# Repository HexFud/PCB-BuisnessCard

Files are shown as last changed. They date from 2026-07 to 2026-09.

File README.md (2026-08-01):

## PCB-Badge

I built this electronic badge that can be used for example in hachatons or other IT event if you open the project on KICAD you can also customize the writings.

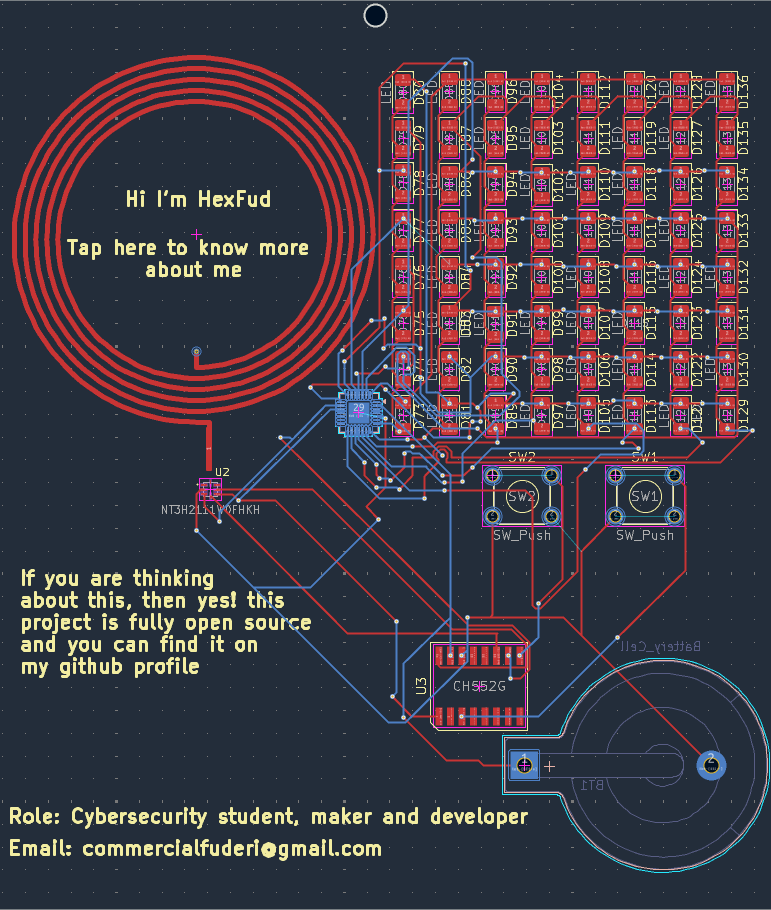
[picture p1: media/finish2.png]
Final work


## How this was made

This project consists only of one PCB 85x100mm and other components like the led matrix controller the microcontoller etc. It also has a NFC tag that can be written with the microcontroller and 2 minigames showed on the 8x8 led matrix on the front.

## How to flash the firmware

1. Install Arduino IDE
   
2. Add the board package going into File -> Preferences and in the additional board URL you paste this https://raw.githubusercontent.com/DeqingSun/ch55xduino/ch55xduino/package_ch55xduino_mcs51_index.json
  
3. Navigate to Tools -> Board -> Boards Manager search ch55xduino and click install
   
4. Plug the microcontroller into the pc and select the correct board you are using in my case a CH552
   
5. You can now flash the firmware

## Notes

If you want to bring your own game on the PCB you're welcome! just fork this repository and then if i'll like your work i am going to mention you guys in the original code. Unfortunatley we only have 2 buttons but in the future I can design another PCB with more functions

## AI decleration

Ai helped me to build the part of the firmware that controls the LED matrix

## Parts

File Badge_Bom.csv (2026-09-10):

Item | Quantity | Unit Price (EUR) | Total Price (EUR) | Unit Price (USD) | Total Price (USD)
IS31FL3731 LED Matrix Driver | 1 | 20.00 | 20.00 | 23.24 | 23.24
NT3H2111W0FHKH NFC IC | 1 | 25.00 | 25.00 | 29.06 | 29.06
CH552G Microcontroller | 1 | 11.00 | 11.00 | 12.78 | 12.78
LED 0603 | 64 | 0.125 | 8.00 | 0.145 | 9.30
Tactile Push Button SMD | 2 | 5.00 | 10.00 | 5.81 | 11.62
Battery Holder Keystone 103 | 1 | 12.00 | 12.00 | 13.95 | 13.95
PCB | 1 | 90.00 | 90.00 | 104.60 | 104.60
TOTAL |  |  | 176.00 |  | 204.55

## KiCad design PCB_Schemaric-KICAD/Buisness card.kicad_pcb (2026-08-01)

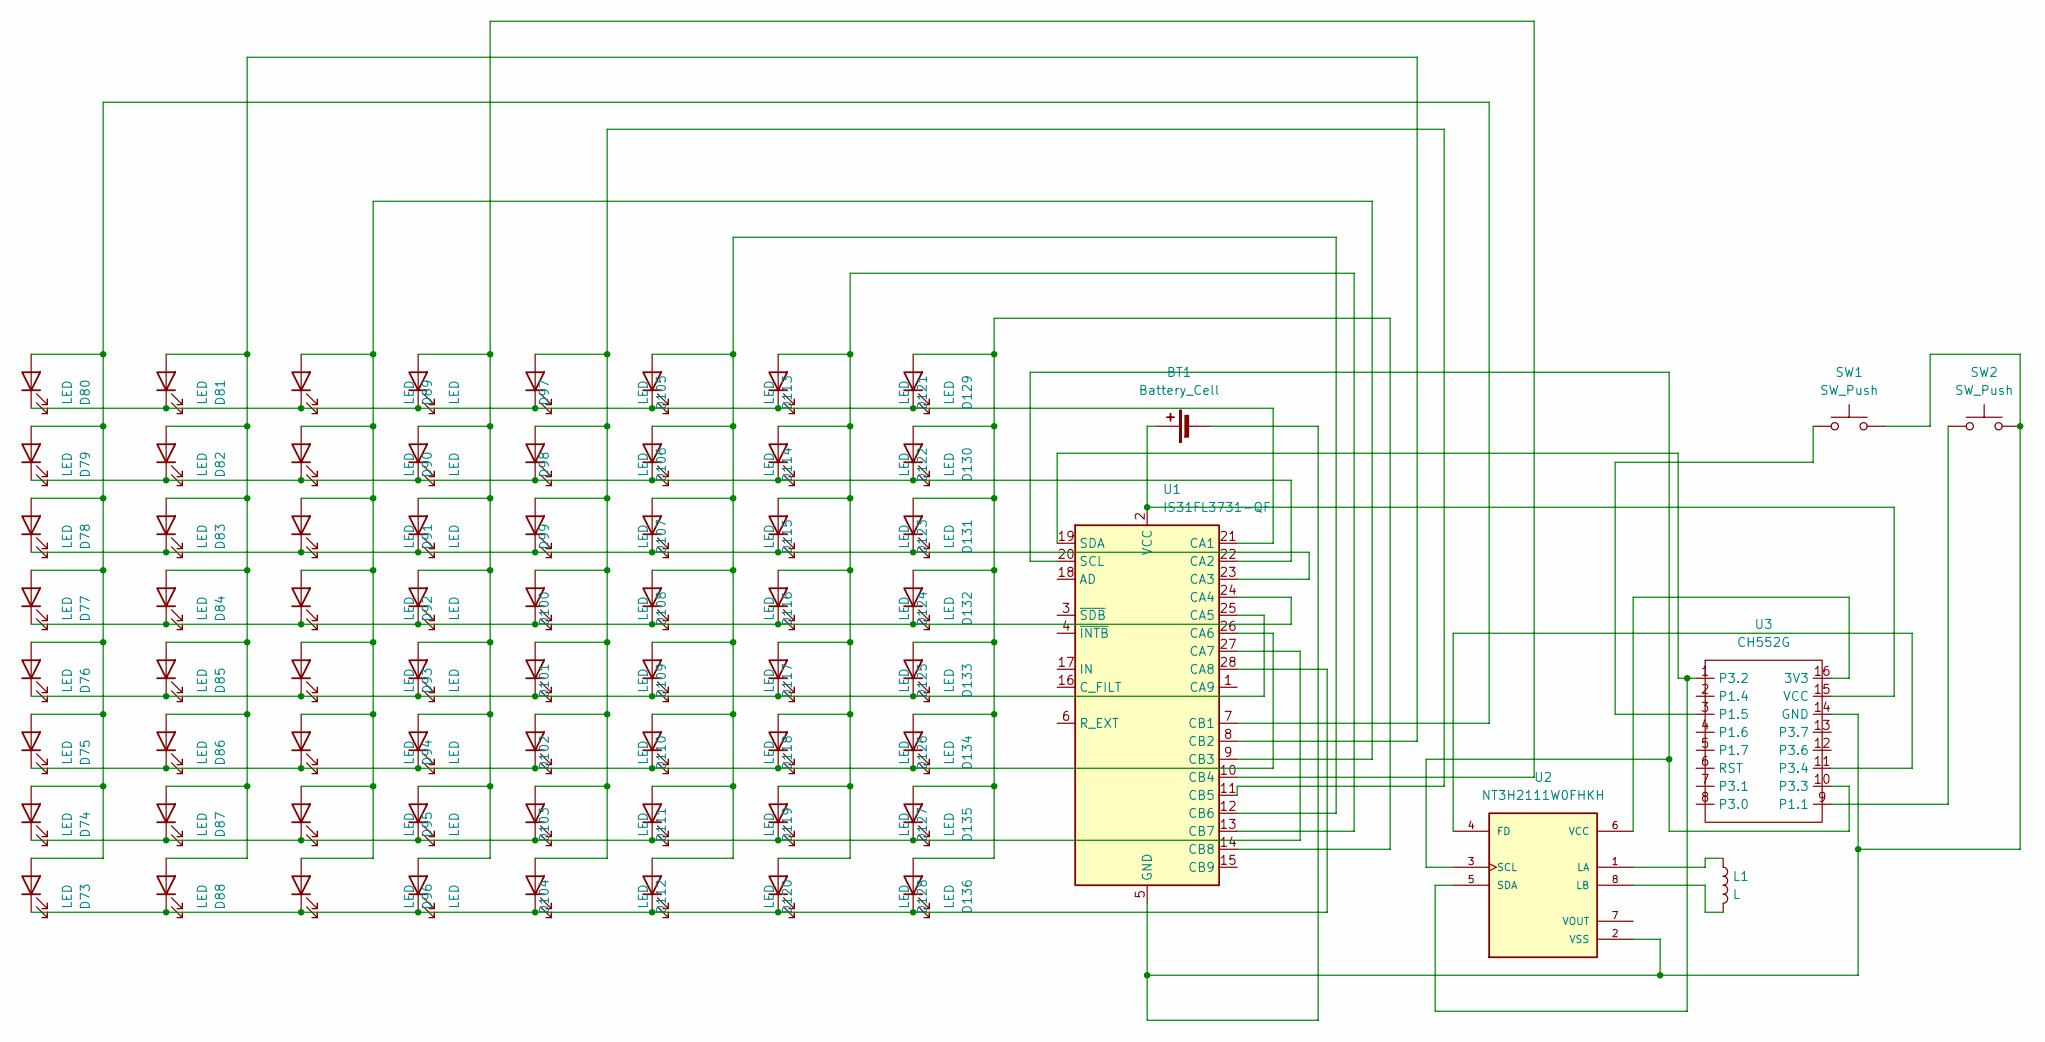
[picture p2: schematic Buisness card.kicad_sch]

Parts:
BT1: Battery_Cell; BatteryHolder_Keystone_103_1x20mm
D73, D74, D75, D76, D77, D78, D79, D80, D81, D82, D83, D84, D85, D86, D87, D88, D89, D90, D91, D92, D93, D94, D95, D96, D97, D98, D99, D100, D101, D102, D103, D104, D105, D106, D107, D108, D109, D110, D111, D112, D113, D114, D115, D116, D117, D118, D119, D120, D121, D122, D123, D124, D125, D126, D127, D128, D129, D130, D131, D132, D133, D134, D135, D136: LED; LED_1206_3216Metric
L1: L; COIL_GENERATOR
SW1, SW2: SW_Push; SW_TH_Tactile_Omron_B3F-102x
U1: IS31FL3731-QF; QFN-28-1EP_4x4mm_P0.4mm_EP2.3x2.3mm
U2: NT3H2111W0FHKH; QFN8P50_160X160X50L40X20N
U3: CH552G

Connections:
unnamed: BT1.1 (+), U1.2 (VCC), U3.15 (VCC)
unnamed: BT1.2 (-), SW1.2, SW2.2, U1.5 (GND), U1.29 (GND), U2.2 (VSS), U3.14 (GND)
unnamed: D73.2 (A), D74.2 (A), D75.2 (A), D76.2 (A), D77.2 (A), D78.2 (A), D79.2 (A), D80.2 (A), U1.7 (CB1)
unnamed: D81.2 (A), D82.2 (A), D83.2 (A), D84.2 (A), D85.2 (A), D86.2 (A), D87.2 (A), D88.2 (A), U1.8 (CB2)
unnamed: D89.2 (A), D90.2 (A), D91.2 (A), D92.2 (A), D93.2 (A), D94.2 (A), D95.2 (A), D96.2 (A), U1.9 (CB3)
unnamed: D97.2 (A), D98.2 (A), D99.2 (A), D100.2 (A), D101.2 (A), D102.2 (A), D103.2 (A), D104.2 (A), U1.10 (CB4)
unnamed: D77.1 (K), D84.1 (K), D92.1 (K), D100.1 (K), D108.1 (K), D116.1 (K), D124.1 (K), D132.1 (K), U1.24 (CA4)
unnamed: D76.1 (K), D85.1 (K), D93.1 (K), D101.1 (K), D109.1 (K), D117.1 (K), D125.1 (K), D133.1 (K), U1.25 (CA5)
unnamed: D75.1 (K), D86.1 (K), D94.1 (K), D102.1 (K), D110.1 (K), D118.1 (K), D126.1 (K), D134.1 (K), U1.26 (CA6)
unnamed: D74.1 (K), D87.1 (K), D95.1 (K), D103.1 (K), D111.1 (K), D119.1 (K), D127.1 (K), D135.1 (K), U1.27 (CA7)
unnamed: D73.1 (K), D88.1 (K), D96.1 (K), D104.1 (K), D112.1 (K), D120.1 (K), D128.1 (K), D136.1 (K), U1.28 (CA8)
unnamed: D105.2 (A), D106.2 (A), D107.2 (A), D108.2 (A), D109.2 (A), D110.2 (A), D111.2 (A), D112.2 (A), U1.11 (CB5)
unnamed: D80.1 (K), D81.1 (K), D89.1 (K), D97.1 (K), D105.1 (K), D113.1 (K), D121.1 (K), D129.1 (K), U1.21 (CA1)
unnamed: D79.1 (K), D82.1 (K), D90.1 (K), D98.1 (K), D106.1 (K), D114.1 (K), D122.1 (K), D130.1 (K), U1.22 (CA2)
unnamed: D78.1 (K), D83.1 (K), D91.1 (K), D99.1 (K), D107.1 (K), D115.1 (K), D123.1 (K), D131.1 (K), U1.23 (CA3)
unnamed: D113.2 (A), D114.2 (A), D115.2 (A), D116.2 (A), D117.2 (A), D118.2 (A), D119.2 (A), D120.2 (A), U1.12 (CB6)
unnamed: D121.2 (A), D122.2 (A), D123.2 (A), D124.2 (A), D125.2 (A), D126.2 (A), D127.2 (A), D128.2 (A), U1.13 (CB7)
unnamed: D129.2 (A), D130.2 (A), D131.2 (A), D132.2 (A), D133.2 (A), D134.2 (A), D135.2 (A), D136.2 (A), U1.14 (CB8)
unnamed: U1.20 (SCL), U2.3 (SCL), U3.10 (P3.3)
unnamed: U1.19 (SDA), U2.5 (SDA), U3.1 (P3.2)
unnamed: U2.4 (FD), U3.11 (P3.4)
unnamed: L1.1, U2.1 (LA)
unnamed: L1.2, U2.8 (LB)
unnamed: U2.6 (VCC), U3.16 (3V3)
unnamed: SW2.1, U3.9 (P1.1)
unnamed: SW1.1, U3.3 (P1.5)

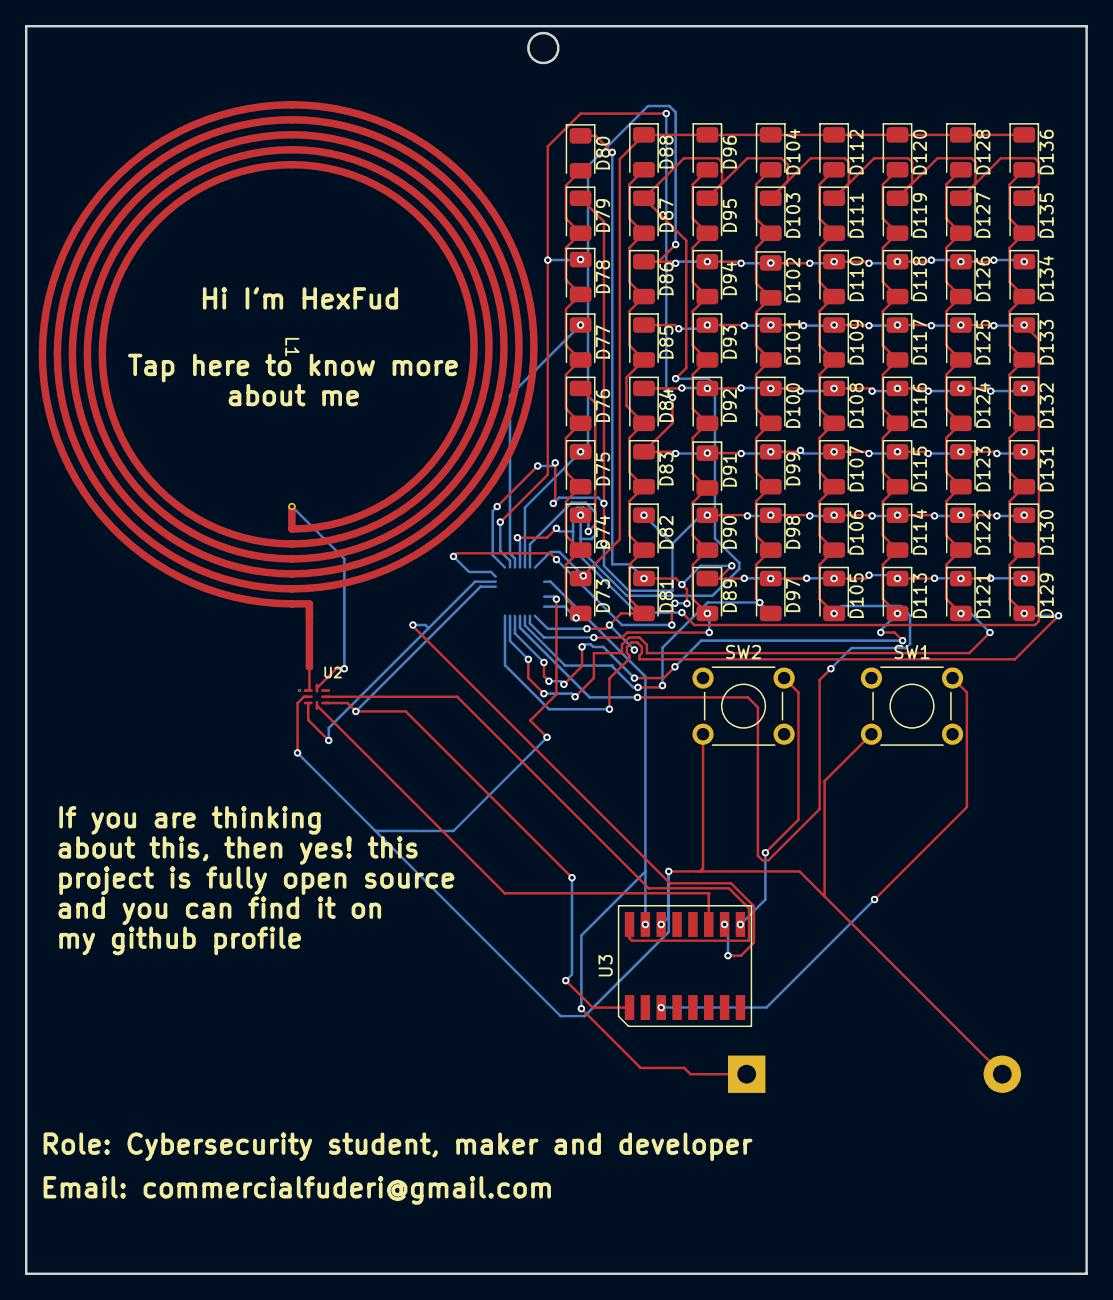
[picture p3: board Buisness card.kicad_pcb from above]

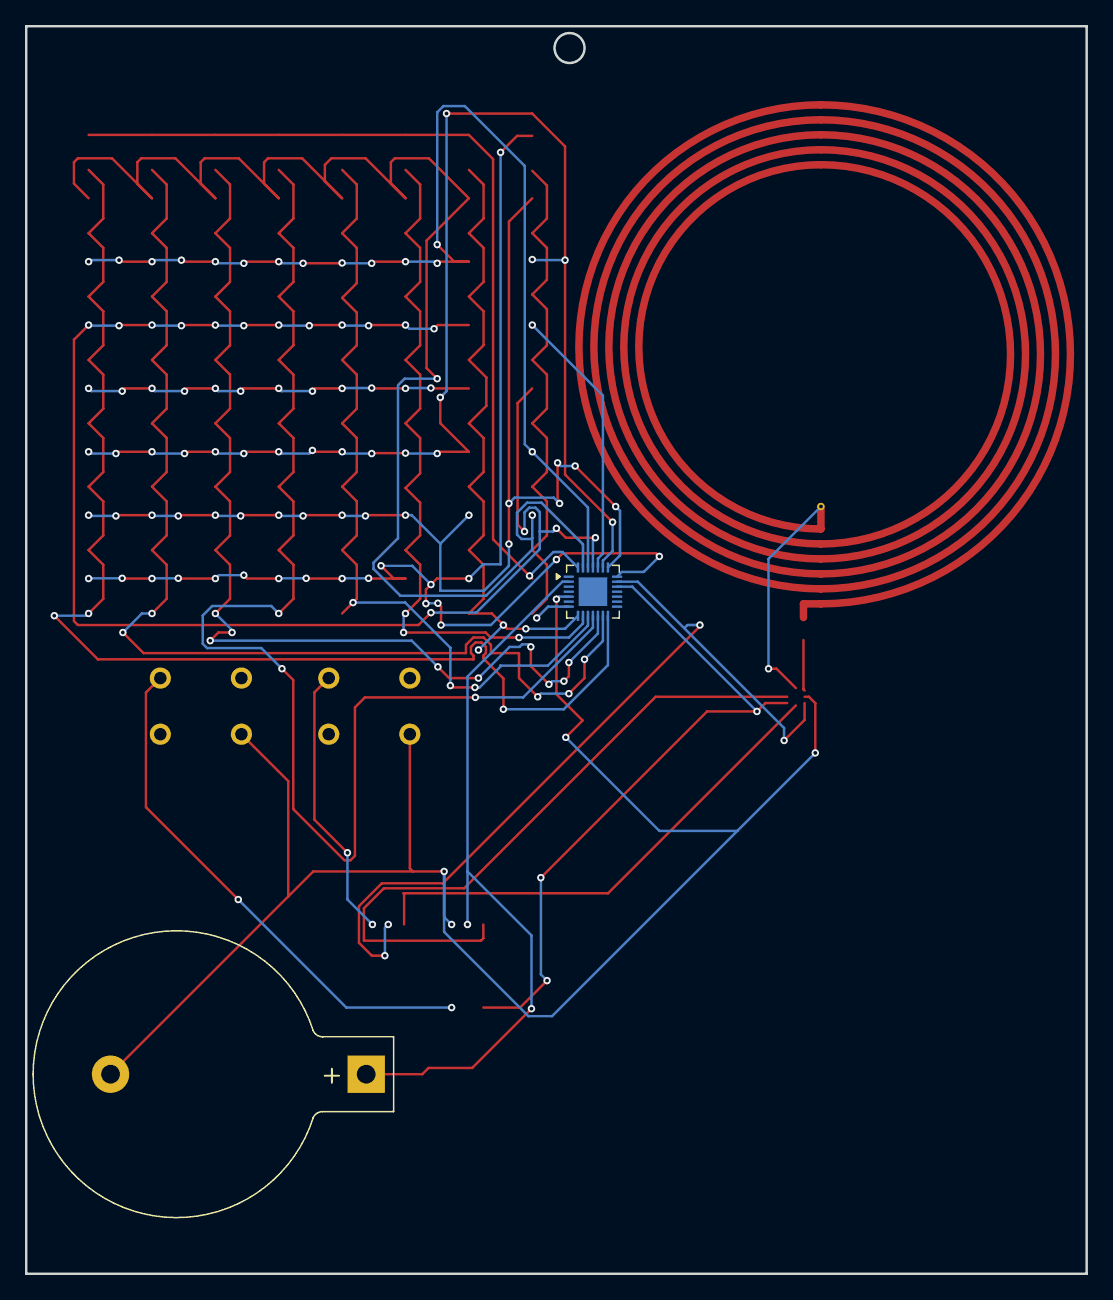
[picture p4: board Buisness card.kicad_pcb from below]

Board: 2 copper layers, 85.0 x 100.0 mm, 71 parts (2 on the bottom side), 26 nets.

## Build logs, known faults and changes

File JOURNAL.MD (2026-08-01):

---
title: "PCB-BuisnessCard"
author: "HexFud"
description: "This will be a pcb style business card with some functions like a little game and maybe a screen"
created_at: "2025-07-31"
---

## Day 1 (31 July 2026)

Started to place down some components in kicad but I am still confused on what microcontroller to chose. I need to find something small that has a lot of gpio pins, my first tought is the CH552G because it also has a usb-c port that can be used for flsahing the firmware on the buisness card 

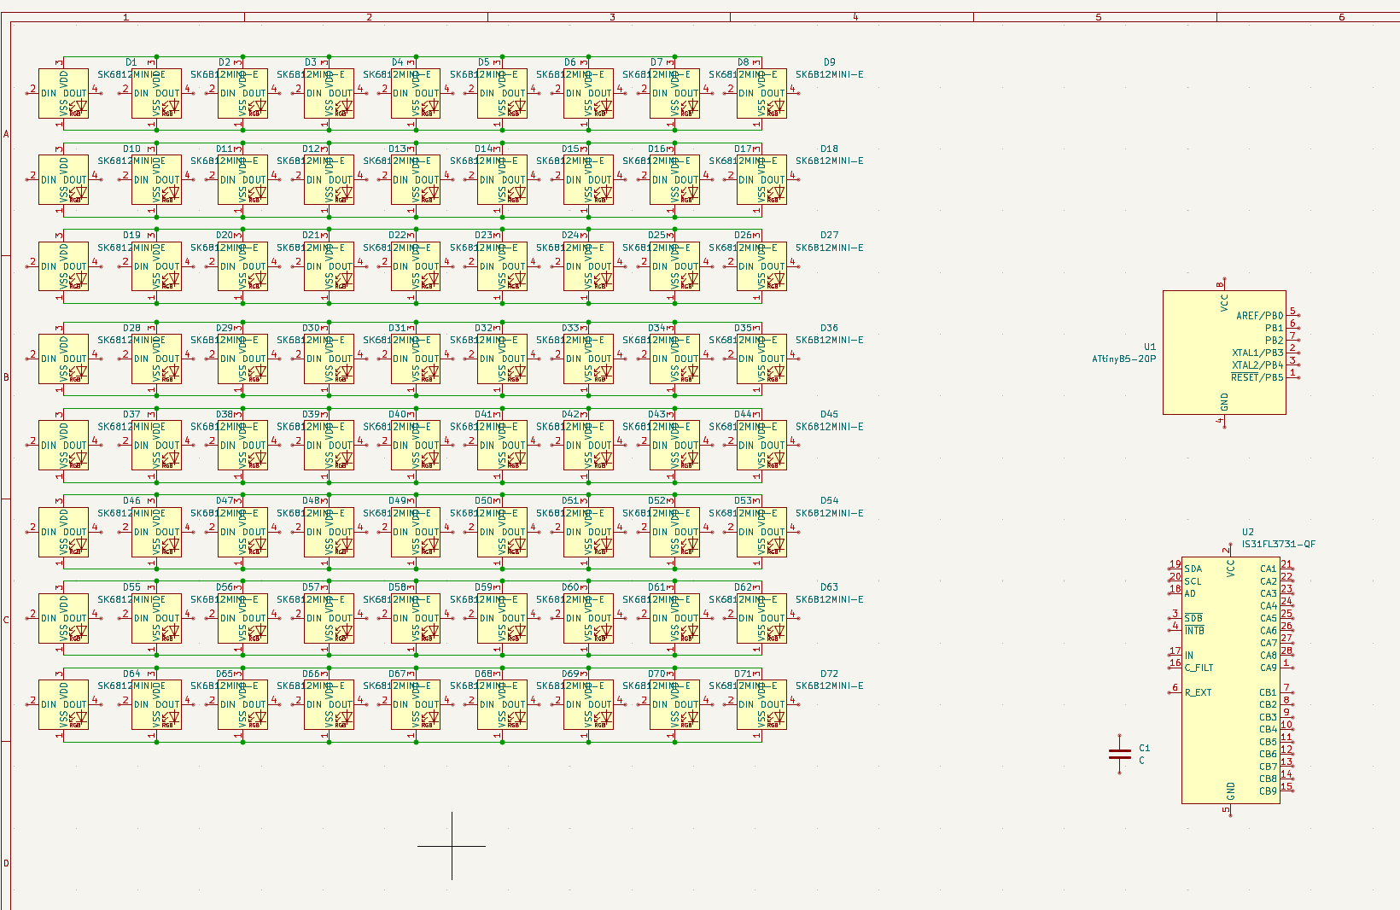
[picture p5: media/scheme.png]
schematics


After reading about the microcontroller i finally chose the CH522G, but now i need to change the LEDs because the one i chose are too big and power consuming for what i need to build so i chose something smaller (APT1608)
Update: I decided to build a sort of screen made of LEDs putting on the board an 8x8 led matrix driven by a IS31FL3731-QF led controller. Initially i tought about a single input for all the LED's but while i was wiring them i thought that the couldn' be controlled separately
This is the work in progress matrix:

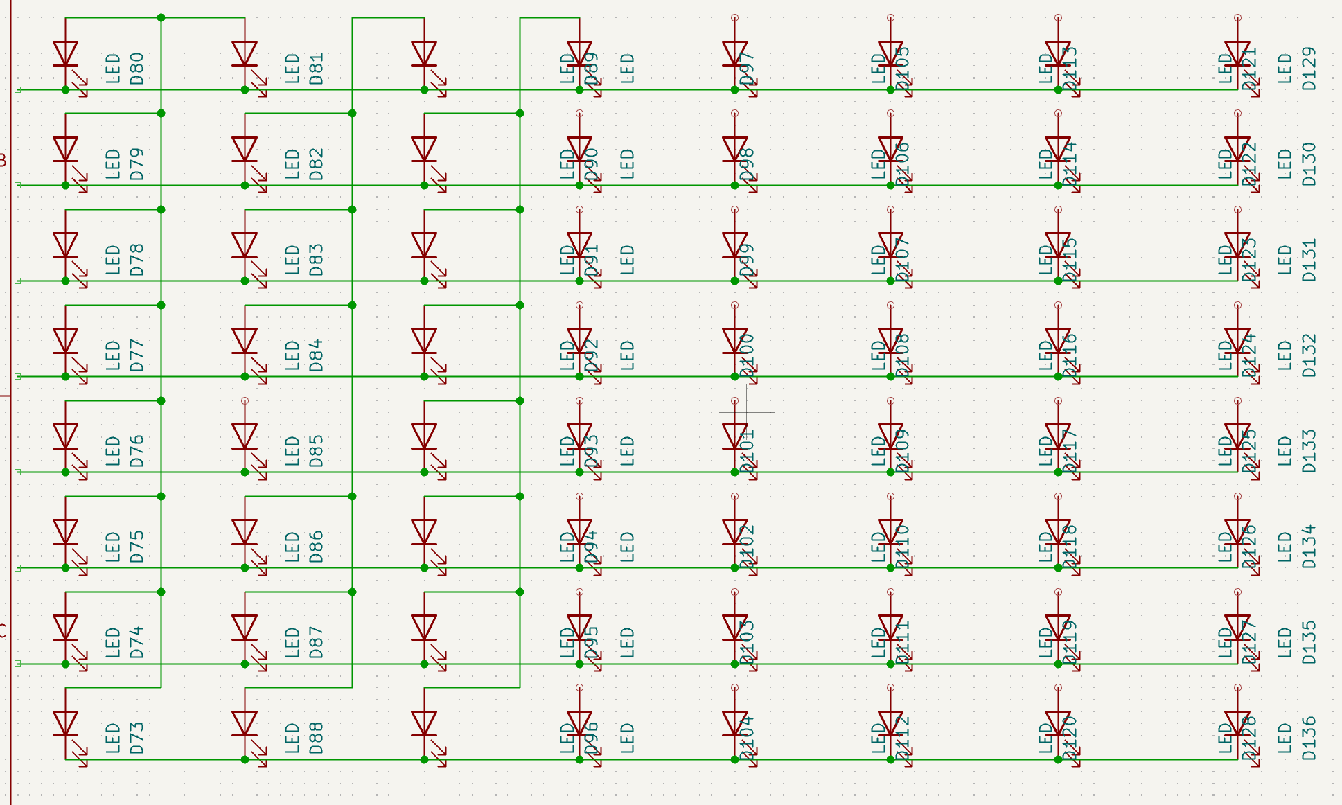
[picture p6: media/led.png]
led matrix


I ran into a problem, I need to decide what nfc reader to use because i want it to be writable by the microcontroller and has a vast compatiblity with all smartphones. I am reading a lot of documentation but i cannot find the right one. I am going to resume wiring without the nfc reader and add it later

I have now assigned the footprints for all the components and i have to place it in order, i am trying to keep things as small as possible because it is still a badge :)

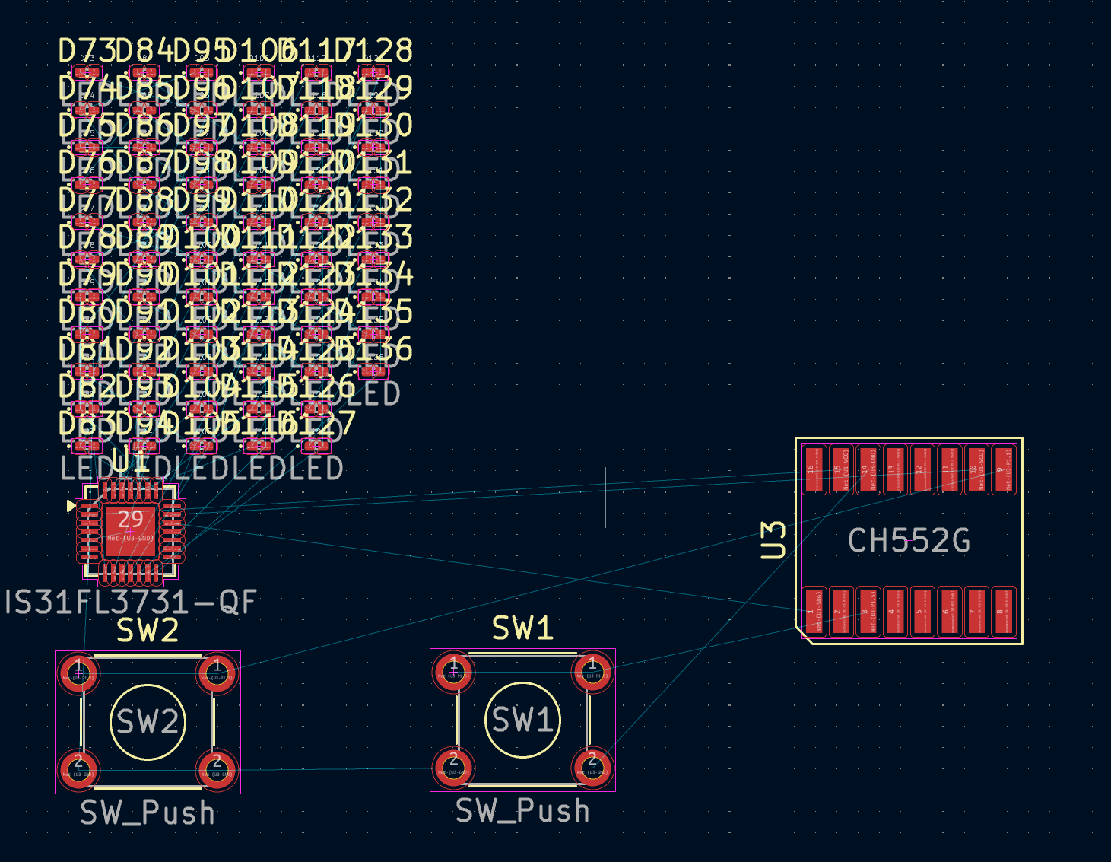
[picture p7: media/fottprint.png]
footprint


Finally finished placing the led footprints in a matrix shape (needed to check evry space between them), now i think it is time to check again for the nfc reader/antenna to complete the schematic (maybe I will have more luck)

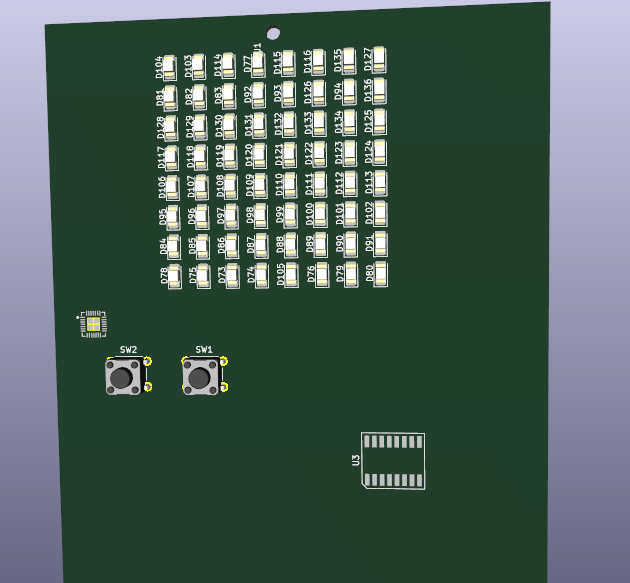
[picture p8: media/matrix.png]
matrix


Finally found the nfc/rfid reader and also the footprint! Now i need to wire it to the other components.

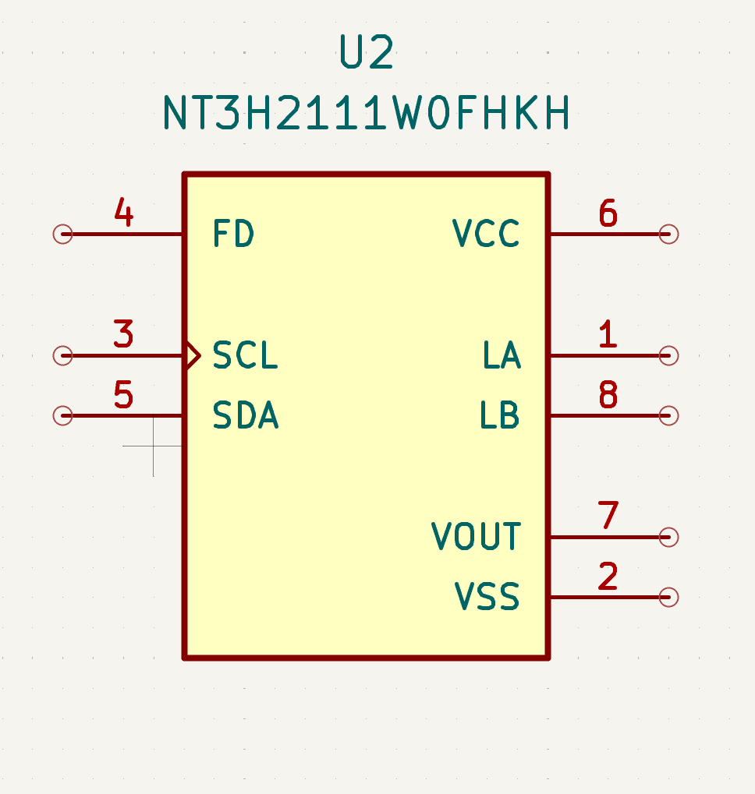
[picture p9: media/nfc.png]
nfc reader


After looking at the wiring path of the leds i noticed that the matrix in the elctrical scheme was totally right but when i started placing the leds on the PCB i didn't put them in order as the scheme. So now i am going to re-order the leds like the schematic to get a more efficient wiring.
Update: After a bit of rotating, moving and replacing LEDs i finally ordered them like the schematic now i can finally start wiring

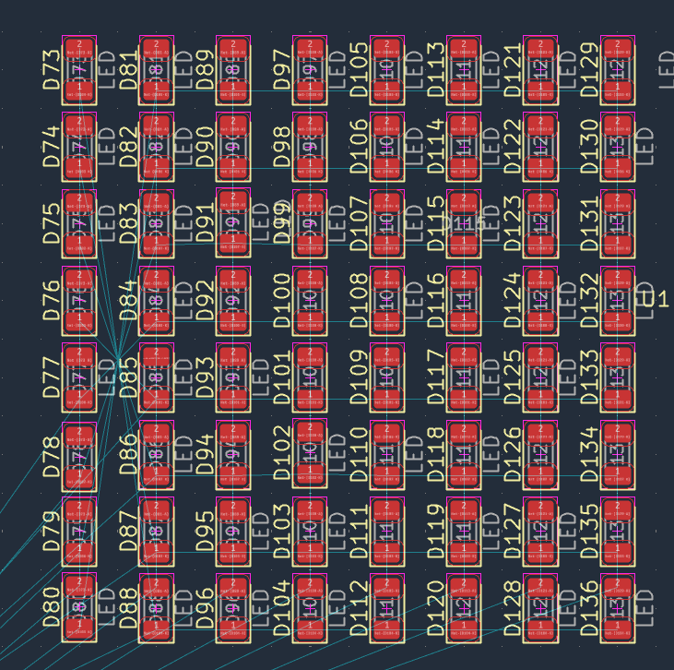
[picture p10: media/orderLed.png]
Ordered LEDs


Finished wiring the LED matrix, now i will start to wire the matrix to the led controller

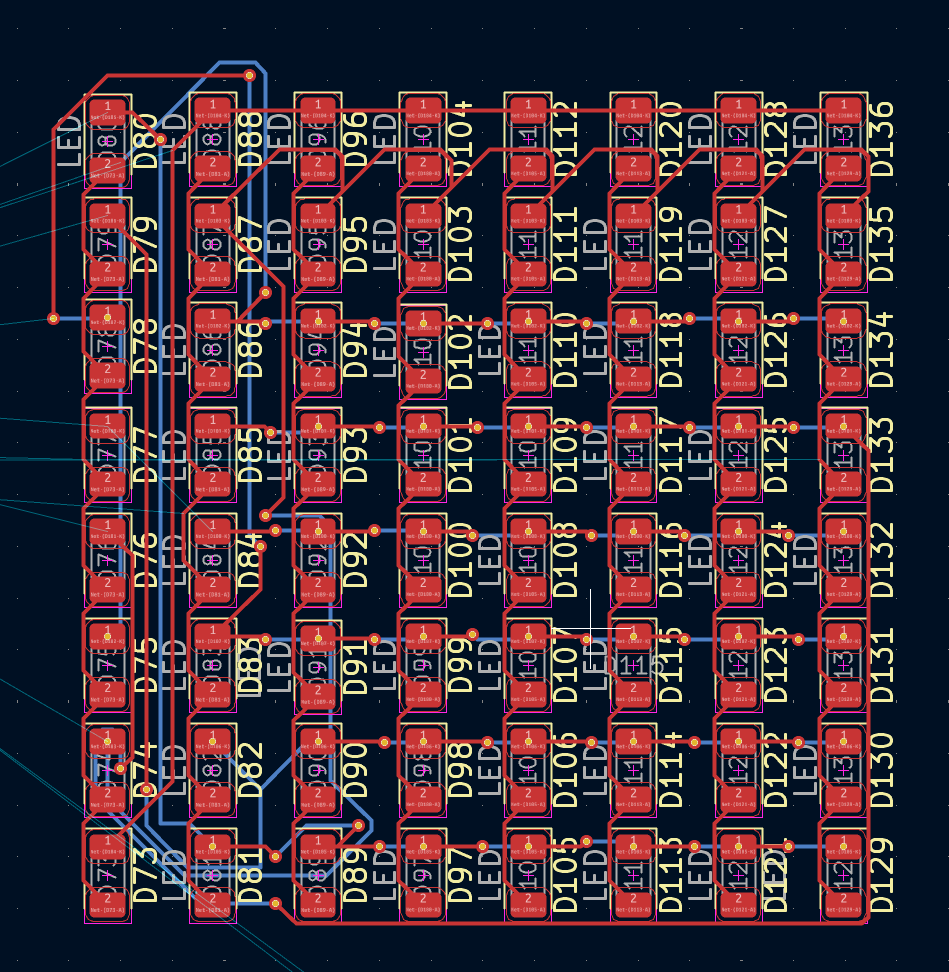
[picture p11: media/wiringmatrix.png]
LED wiring


After searching about and learning more about led matrixes just to confirm my wiring scheme and i ran into a site that said that i need pull-up resistors for the LEDs, so know i am going to wire them and then contniue my jouney. Furthermore i forgot to add the button battery holder to keep the pcb alive even if it is not connected to the usb

Added a button battery and i think i will end the day with this modification. I will continue tomorrow
Update: Sike! I placed all the components in order for the PCB also added a coil as the antenna for the NFC! Now i need to wire all the parts together and then start designing the firmware

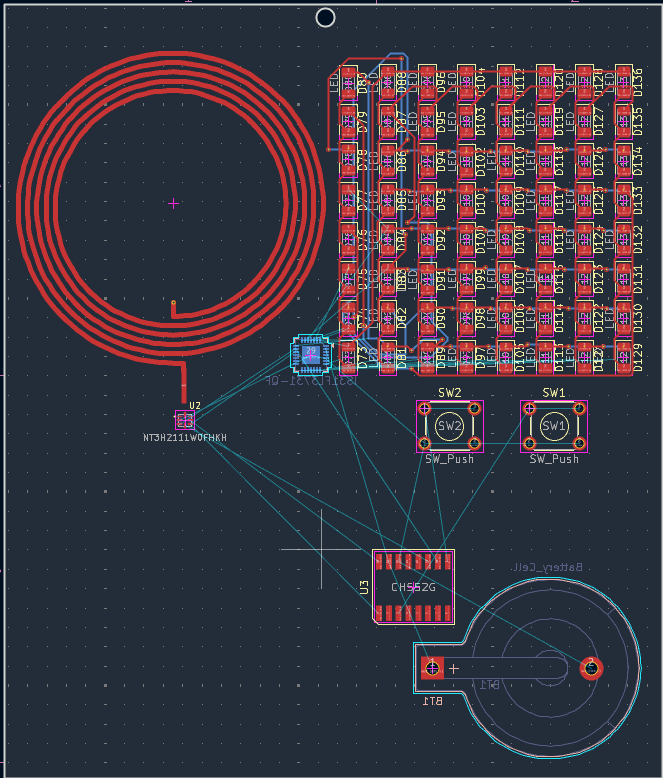
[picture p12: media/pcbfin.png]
Almost finished PCB


## DAY 2 (1 August 2026)

Finally finished the PCB!!! Now i will upload all the pcb and scheme files here and I will start do develop the microcontroller firmware

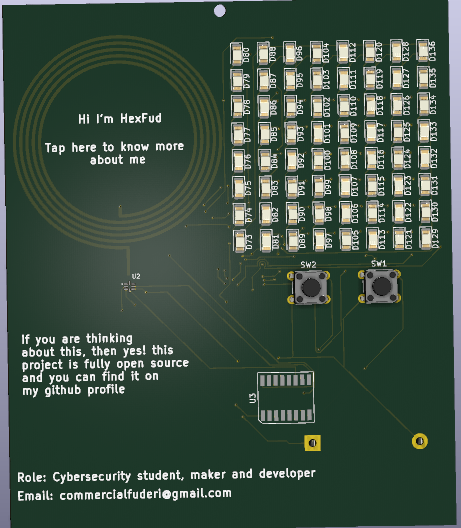
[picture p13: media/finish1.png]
LED wiring 

The firmawre is done! Now I need to do some final checks and the project is officaly finished

I officially uploaded all of the files on github! So this project is officially closed for now, maybe in the future i will do some re-design.

Total time spent: 5 hours

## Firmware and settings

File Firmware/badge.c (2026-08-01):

#include <ch552.h>
#include <stdint.h>
#include <stdlib.h>

#define SDA_PIN   P3_2
#define SCL_PIN   P3_3
#define SW1_PIN   P1_1
#define SW2_PIN   P1_5

#define ADDR_IS31FL3731   0x74

#define IS31_REG_CONFIG_BANK  0xFD
#define IS31_BANK_FUNCTION    0x0B
#define IS31_REG_SHUTDOWN     0x0A
#define IS31_REG_PICTURE_DISP 0x01
#define IS31_FRAME0_ONOFF     0x00
#define IS31_FRAME0_PWM       0x24

static void delay_us(uint16_t us) {
    while (us--) {
        __asm nop __endasm; __asm nop __endasm;
        __asm nop __endasm; __asm nop __endasm;
    }
}
static void delay_ms(uint16_t ms) { while (ms--) delay_us(1000); }

static void i2c_sda_high(void) { SDA_PIN = 1; }
static void i2c_sda_low(void)  { SDA_PIN = 0; }
static void i2c_scl_high(void) { SCL_PIN = 1; }
static void i2c_scl_low(void)  { SCL_PIN = 0; }

static void i2c_start(void) {
    i2c_sda_high(); i2c_scl_high(); delay_us(3);
    i2c_sda_low();  delay_us(3);
    i2c_scl_low();  delay_us(3);
}
static void i2c_stop(void) {
    i2c_sda_low(); delay_us(3);
    i2c_scl_high(); delay_us(3);
    i2c_sda_high(); delay_us(3);
}
static uint8_t i2c_write_byte(uint8_t b) {
    uint8_t i, ack;
    for (i = 0; i < 8; i++) {
        if (b & 0x80) i2c_sda_high(); else i2c_sda_low();
        b <<= 1;
        delay_us(2);
        i2c_scl_high(); delay_us(3);
        i2c_scl_low();  delay_us(2);
    }
    i2c_sda_high(); delay_us(2);
    i2c_scl_high(); delay_us(2);
    ack = (SDA_PIN == 0);
    i2c_scl_low(); delay_us(2);
    return ack;
}
static void i2c_write_reg(uint8_t addr7, uint8_t reg, uint8_t val) {
    i2c_start();
    i2c_write_byte((addr7 << 1) | 0);
    i2c_write_byte(reg);
    i2c_write_byte(val);
    i2c_stop();
}

static void is31_select_bank(uint8_t bank) {
    i2c_write_reg(ADDR_IS31FL3731, IS31_REG_CONFIG_BANK, bank);
}
static void is31_init(void) {
    uint8_t i;
    is31_select_bank(IS31_BANK_FUNCTION);
    i2c_write_reg(ADDR_IS31FL3731, IS31_REG_SHUTDOWN, 0x01);
    delay_ms(10);
    i2c_write_reg(ADDR_IS31FL3731, IS31_REG_PICTURE_DISP, 0x00);
    is31_select_bank(0x00);
    for (i = 0; i < 18; i++)
        i2c_write_reg(ADDR_IS31FL3731, IS31_FRAME0_ONOFF + i, 0xFF);
}
static void is31_set_led(uint8_t r, uint8_t c, uint8_t pwm) {
    uint8_t reg = IS31_FRAME0_PWM + (r * 16) + c;
    is31_select_bank(0x00);
    i2c_write_reg(ADDR_IS31FL3731, reg, pwm);
}
static void is31_clear(void) {
    uint8_t r, c;
    for (r = 0; r < 8; r++)
        for (c = 0; c < 8; c++)
            is31_set_led(r, c, 0);
}

static uint8_t sw1_pressed_edge(void) {
    static uint8_t last = 1;
    uint8_t now = SW1_PIN;
    uint8_t edge = (last == 1 && now == 0);
    last = now;
    return edge;
}
static uint8_t sw2_pressed_edge(void) {
    static uint8_t last = 1;
    uint8_t now = SW2_PIN;
    uint8_t edge = (last == 1 && now == 0);
    last = now;
    return edge;
}

static uint8_t frame[8];

static void frame_clear(void) {
    uint8_t r;
    for (r = 0; r < 8; r++) frame[r] = 0;
}
static void frame_set(uint8_t r, uint8_t c, uint8_t on) {
    if (on) frame[r] |= (1 << c);
    else    frame[r] &= ~(1 << c);
}
static uint8_t frame_get(uint8_t r, uint8_t c) {
    return (frame[r] >> c) & 1;
}
static void frame_draw(void) {
    uint8_t r, c;
    for (r = 0; r < 8; r++)
        for (c = 0; c < 8; c++)
            is31_set_led(r, c, frame_get(r, c) ? 0xFF : 0x00);
}

static uint16_t rnd_state = 0xACE1;
static uint8_t rnd8(void) {
    rnd_state ^= rnd_state << 7;
    rnd_state ^= rnd_state >> 9;
    rnd_state ^= rnd_state << 8;
    return (uint8_t)(rnd_state & 0xFF);
}

typedef enum { N, E, S, W } heading_t;

#define MAX_SNAKE 64
static int8_t snake_r[MAX_SNAKE];
static int8_t snake_c[MAX_SNAKE];
static uint8_t snake_len;
static heading_t heading;
static int8_t food_r, food_c;

static void spawn_food(void) {
    uint8_t ok;
    do {
        ok = 1;
        food_r = rnd8() & 0x07;
        food_c = rnd8() & 0x07;
        for (uint8_t i = 0; i < snake_len; i++)
            if (snake_r[i] == food_r && snake_c[i] == food_c) ok = 0;
    } while (!ok);
}

static void snake_reset(void) {
    snake_len = 3;
    snake_r[0] = 4; snake_c[0] = 4;
    snake_r[1] = 4; snake_c[1] = 3;
    snake_r[2] = 4; snake_c[2] = 2;
    heading = E;
    spawn_food();
}

static void snake_turn_left(void)  { heading = (heading == N) ? W : heading - 1; }
static void snake_turn_right(void) { heading = (heading == W) ? N : heading + 1; }

static uint8_t snake_step(void) {
    int8_t nr = snake_r[0], nc = snake_c[0];
    uint8_t i, grow;

    if (heading == N) nr--;
    else if (heading == S) nr++;
    else if (heading == E) nc++;
    else nc--;

    if (nr < 0 || nr > 7 || nc < 0 || nc > 7) return 0;

    for (i = 0; i < snake_len; i++)
        if (snake_r[i] == nr && snake_c[i] == nc) return 0;

    grow = (nr == food_r && nc == food_c);

    for (i = (grow ? snake_len : (uint8_t)(snake_len - 1)); i > 0; i--) {
        snake_r[i] = snake_r[i-1];
        snake_c[i] = snake_c[i-1];
    }
    snake_r[0] = nr; snake_c[0] = nc;
    if (grow) {
        if (snake_len < MAX_SNAKE) snake_len++;
        spawn_food();
    }
    return 1;
}

static void snake_draw(void) {
    uint8_t i;
    frame_clear();
    frame_set(food_r, food_c, 1);
    for (i = 0; i < snake_len; i++)
        frame_set(snake_r[i], snake_c[i], 1);
    frame_draw();
}

static void game_over_blink(void) {
    uint8_t i, r, c;
    for (i = 0; i < 4; i++) {
        for (r = 0; r < 8; r++)
            for (c = 0; c < 8; c++)
                is31_set_led(r, c, 0xFF);
        delay_ms(150);
        is31_clear();
        delay_ms(150);
    }
}

static void play_snake(void) {
    uint16_t tick_ms = 300;
    snake_reset();
    while (1) {
        if (sw1_pressed_edge()) snake_turn_left();
        if (sw2_pressed_edge()) snake_turn_right();

        if (!snake_step()) {
            game_over_blink();
            return;
        }
        snake_draw();
        delay_ms(tick_ms);
    }
}

static void play_catch(void) {
    uint16_t timeout_ms = 1500;
    uint16_t elapsed;
    uint8_t tr, tc;

    frame_clear(); frame_draw();
    delay_ms(300);

    while (1) {
        tr = rnd8() & 0x07;
        tc = rnd8() & 0x07;
        frame_clear();
        frame_set(tr, tc, 1);
        frame_draw();

        elapsed = 0;
        while (elapsed < timeout_ms) {
            if (sw1_pressed_edge()) {

                if (timeout_ms > 300) timeout_ms -= 100;
                delay_ms(80);
                break;
            }
            if (sw2_pressed_edge()) {
                return;
            }
            delay_ms(20);
            elapsed += 20;
        }
        if (elapsed >= timeout_ms) {
            game_over_blink();
            return;
        }
    }
}

static void show_menu_icon(uint8_t game_index) {

    frame_clear();
    if (game_index == 0) {

        frame_set(1,1,1); frame_set(1,2,1); frame_set(1,3,1);
        frame_set(2,3,1); frame_set(3,3,1);
        frame_set(3,2,1); frame_set(3,1,1);
        frame_set(4,1,1); frame_set(5,1,1);
        frame_set(5,2,1); frame_set(5,3,1);
    } else {

        frame_set(3,3,1); frame_set(3,4,1);
        frame_set(4,3,1); frame_set(4,4,1);
        frame_set(1,1,1); frame_set(6,6,1);
        frame_set(1,6,1); frame_set(6,1,1);
    }
    frame_draw();
}

void main(void) {
    uint8_t selected = 0;

    SDA_PIN = 1;
    SCL_PIN = 1;
    delay_ms(50);

    is31_init();
    is31_clear();

    while (1) {

        show_menu_icon(selected);
        if (sw2_pressed_edge()) {
            selected = (selected == 0) ? 1 : 0;
            delay_ms(150);
        }
        if (sw1_pressed_edge()) {
            delay_ms(150);
            if (selected == 0) play_snake();
            else               play_catch();
        }
        delay_ms(20);
    }
}
